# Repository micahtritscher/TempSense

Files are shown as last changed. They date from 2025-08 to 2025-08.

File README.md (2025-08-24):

# TempSense - ESP32-C3FH4 temperature logger Rev 0.1
*Micah Tritscher 07/25*

Wireless ESP32-C3FH4 based battery powered HDC1080DMBR temperature and humidty logger, with USB Type-C charging.

### Features
- I2C Texas Instruments HDC1080DMBR humidity and temperature sensor
- Impedance matched PCB antenna from TI AN043 application: https://www.ti.com/lit/an/swra117d/swra117d.pdf
- USB Type-C charging and programming
- BQ24074RGTR charging circuit (Designed for 500 mAh LiPO battery)
- Compact design at 25 mm x 50 mm

### Images
KiCAD 9.0 Renders
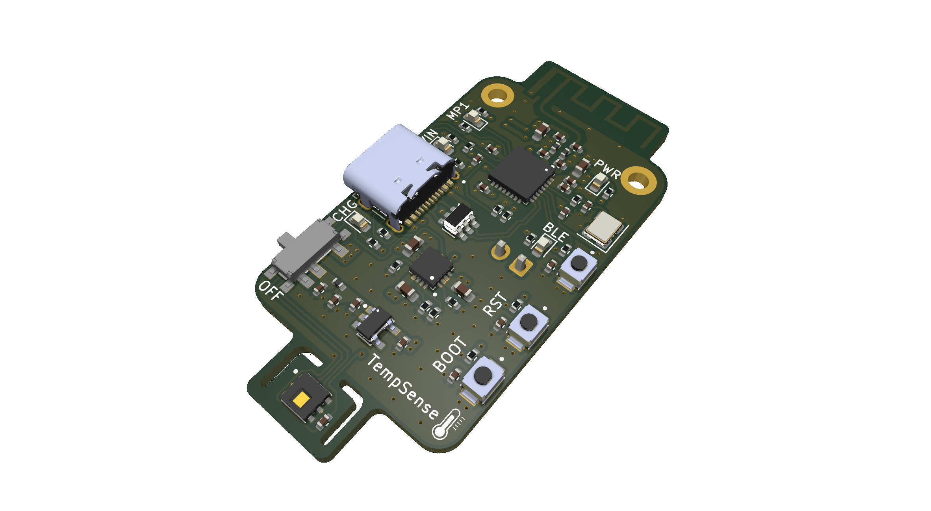
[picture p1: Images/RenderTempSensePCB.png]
PCB Render

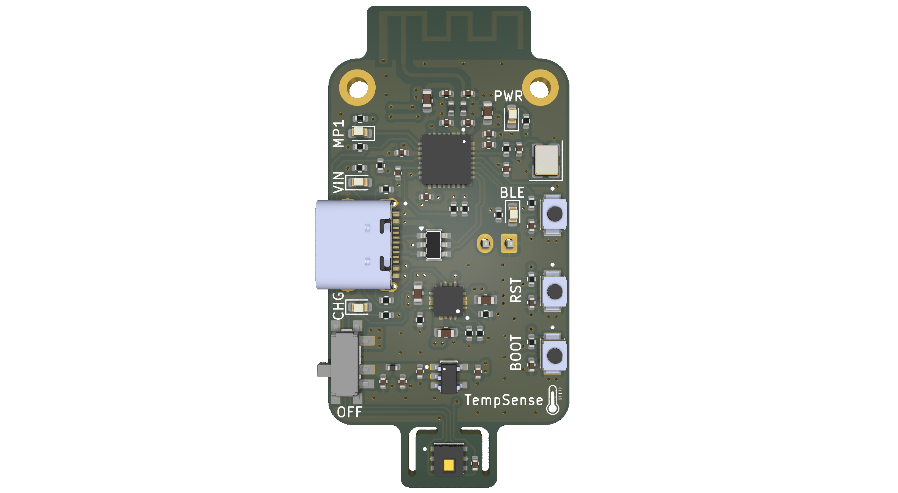
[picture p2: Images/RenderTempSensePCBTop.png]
PCB Render

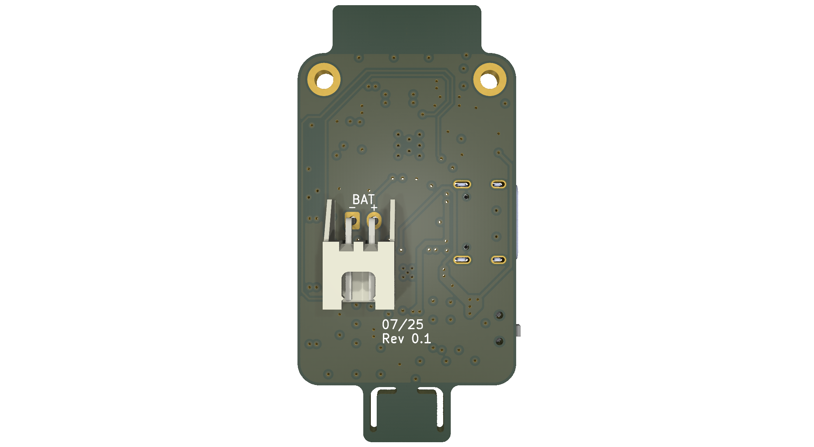
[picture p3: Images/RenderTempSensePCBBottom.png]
PCB Render

Manufactured by JLCPCB, assembled by hand
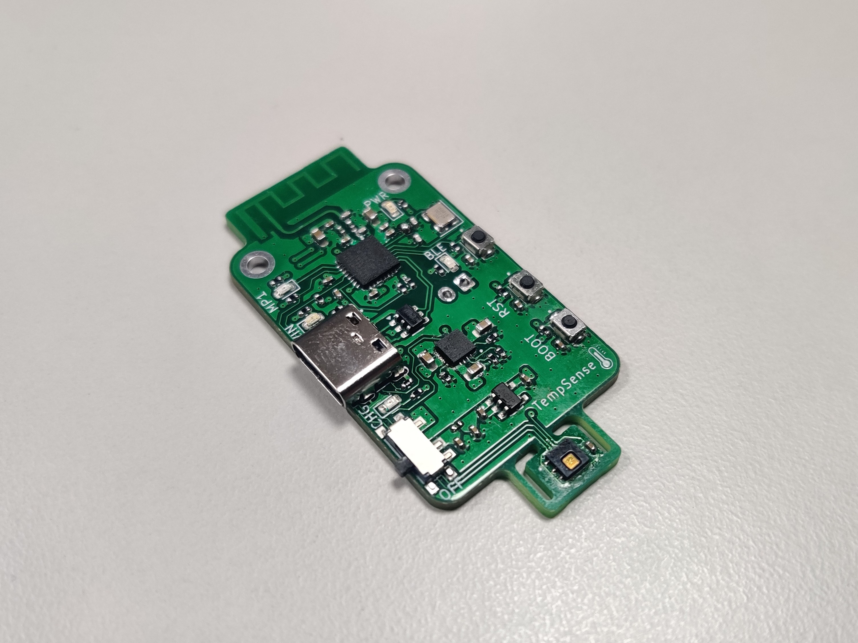
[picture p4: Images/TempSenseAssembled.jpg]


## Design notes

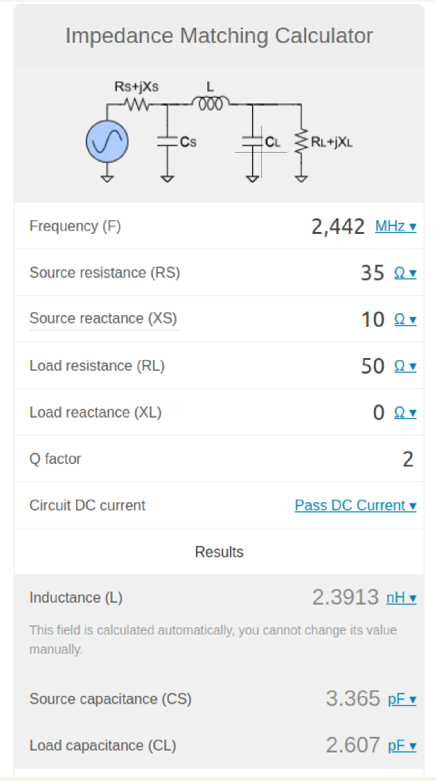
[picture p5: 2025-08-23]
Electrical/Impedance matching network.png

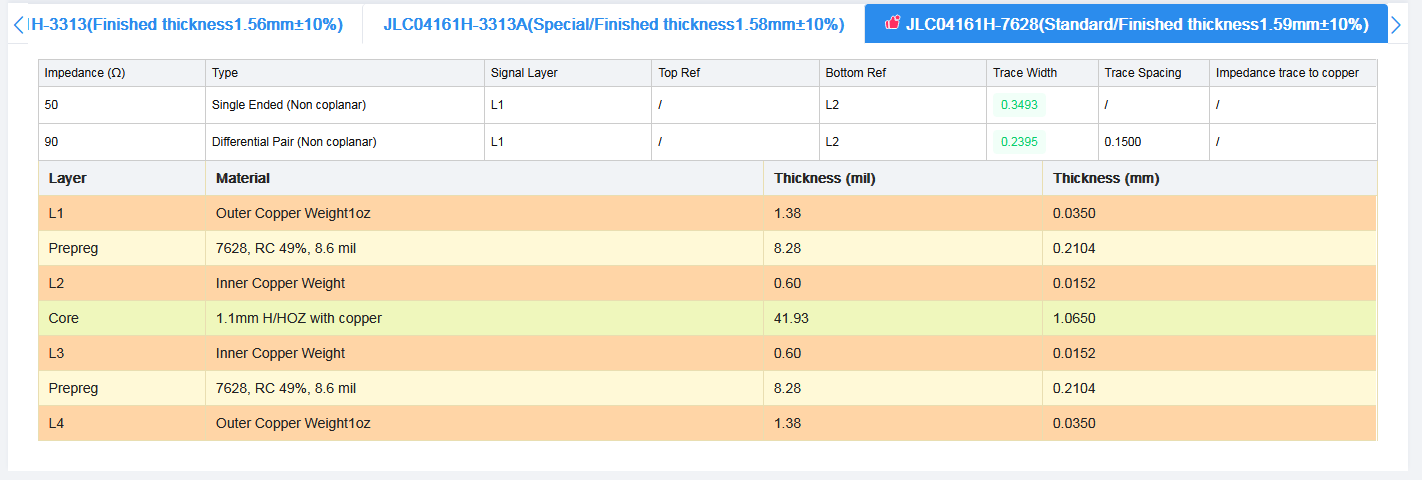
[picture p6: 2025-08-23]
Electrical/Impedance traces calcualtions.png

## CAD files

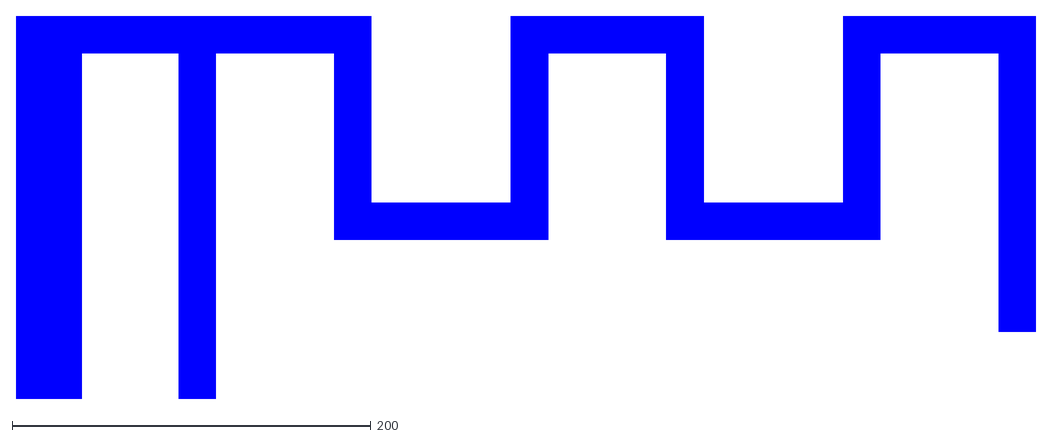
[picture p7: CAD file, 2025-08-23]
Electrical/IFA_USB.dxf
567.9 x 213.2

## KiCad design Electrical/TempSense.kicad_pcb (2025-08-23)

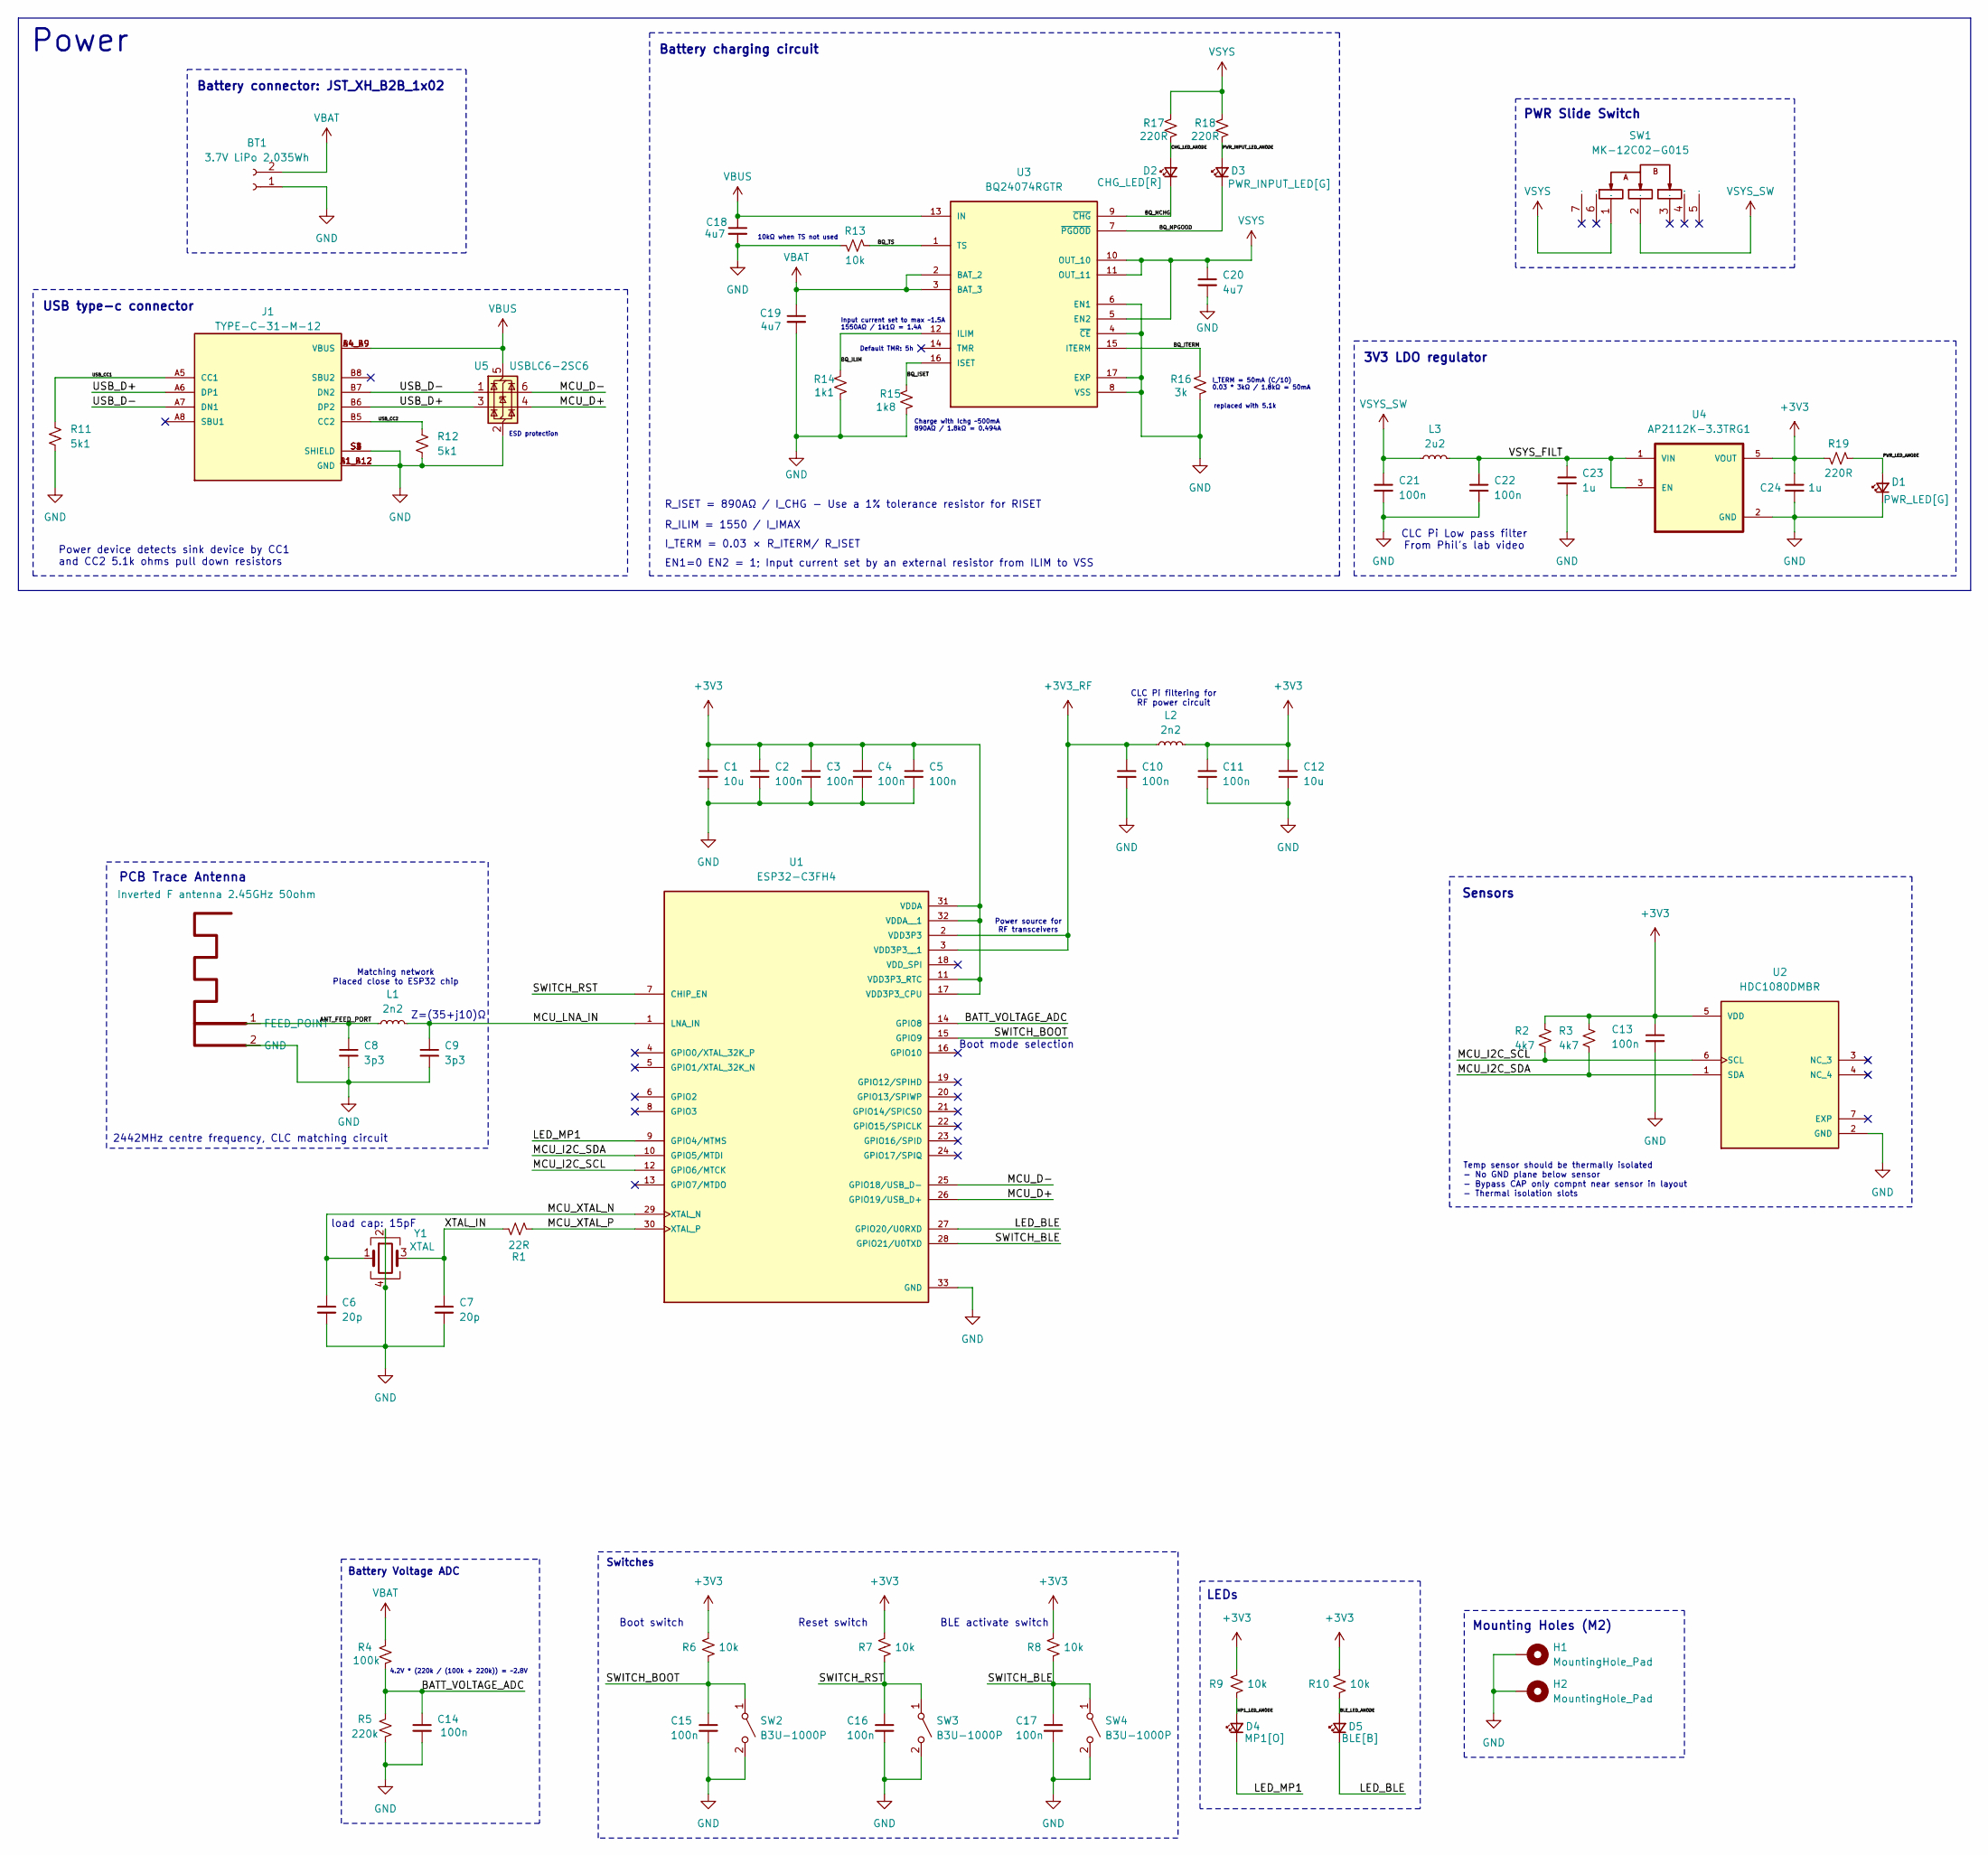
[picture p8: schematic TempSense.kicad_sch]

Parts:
ANT1: Inverted F antenna 2.45GHz 50ohm; Inverted_F_Meandered_Antenna_2.45GHz
BT1: 3.7V LiPo 2.035Wh; JST_XH_S2B-XH-A_1x02_P2.50mm_Horizontal
C1, C12: 10u; C_0603_1608Metric
C2, C3, C4, C5, C10, C11, C13, C14, C15, C16, C17, C21, C22: 100n; C_0402_1005Metric
C6, C7: 20p; C_0402_1005Metric
C8, C9: 3p3; C_0402_1005Metric
C18, C19, C20: 4u7; C_0603_1608Metric
C23, C24: 1u; C_0402_1005Metric
D1: PWR_LED[G]; LED_0603_1608Metric
D2: CHG_LED[R]; LED_0603_1608Metric
D3: PWR_INPUT_LED[G]; LED_0603_1608Metric
D4: MP1[O]; LED_0603_1608Metric
D5: BLE[B]; LED_0603_1608Metric
H1, H2: MountingHole_Pad; MountingHole_2.2mm_M2_DIN965_Pad
J1: TYPE-C-31-M-12; HRO_TYPE-C-31-M-12; PARTREV 2020.12.08
L1, L2: 2n2; L_0402_1005Metric
L3: 2u2; L_0402_1005Metric
R1: 22R; R_0402_1005Metric
R2, R3: 4k7; R_0402_1005Metric
R4: 100k; R_0402_1005Metric
R5: 220k; R_0402_1005Metric
R6, R7, R8, R9, R10, R13: 10k; R_0402_1005Metric
R11, R12: 5k1; R_0402_1005Metric
R14: 1k1; R_0402_1005Metric
R15: 1k8; R_0402_1005Metric
R16: 3k; R_0402_1005Metric
R17, R18, R19: 220R; R_0402_1005Metric
SW1: MK-12C02-G015; SW-SMD_G-SWITCH_MK-12C02-G015; Manufacturer Part MK-12C02-G015
SW2, SW3, SW4: B3U-1000P; SW_B3U-1000P
U1: ESP32-C3FH4; PARTREV 2.0
U2: HDC1080DMBR; PARTREV A
U3: BQ24074RGTR; PARTREV M
U4: AP2112K-3.3TRG1; PARTREV 2-2
U5: USBLC6-2SC6; SOT-23-6
Y1: XTAL; Crystal_SMD_3225-4Pin_3.2x2.5mm

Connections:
+3V3: C1.1, C2.1, C3.1, C4.1, C5.1, C11.1, C12.1, C13.1, C24.1, L2.2, R2.1, R3.1, R6.1, R7.1, R8.1, R9.1, R10.1, R19.2, U1.11 (VDD3P3_RTC), U1.17 (VDD3P3_CPU), U1.31 (VDDA), U1.32 (VDDA__1), U2.5 (VDD), U4.5 (VOUT)
+3V3_RF: C10.1, L2.1, U1.2 (VDD3P3), U1.3 (VDD3P3__1)
/ANT_FEED_PORT: ANT1.1 (FEED_POINT), C8.1, L1.1
/BATT_VOLTAGE_ADC: C14.1, R4.2, R5.1, U1.14 (GPIO8)
/BLE_LED_ANODE: D5.2 (A), R10.2
/BQ_ILIM: R14.2, U3.12 (ILIM)
/BQ_ISET: R15.2, U3.16 (ISET)
/BQ_ITERM: R16.2, U3.15 (ITERM)
/BQ_NCHG: D2.1 (K), U3.9 (~CHG)
/BQ_NPGOOD: D3.1 (K), U3.7 (~PGOOD)
/BQ_TS: R13.1, U3.1 (TS)
/CHG_LED_ANODE: D2.2 (A), R17.2
/LED_BLE: D5.1 (K), U1.27 (GPIO20/U0RXD)
/LED_MP1: D4.1 (K), U1.9 (GPIO4/MTMS)
/MCU_D+: U1.26 (GPIO19/USB_D+), U5.4 (I/O2)
/MCU_D-: U1.25 (GPIO18/USB_D-), U5.6 (I/O1)
/MCU_I2C_SCL: R2.2, U1.12 (GPIO6/MTCK), U2.6 (SCL)
/MCU_I2C_SDA: R3.2, U1.10 (GPIO5/MTDI), U2.1 (SDA)
/MCU_LNA_IN: C9.1, L1.2, U1.1 (LNA_IN)
/MCU_XTAL_N: C6.1, U1.29 (XTAL_N), Y1.1
/MCU_XTAL_P: R1.1, U1.30 (XTAL_P)
/MP1_LED_ANODE: D4.2 (A), R9.2
/PWR_INPUT_LED_ANODE: D3.2 (A), R18.2
/PWR_LED_ANODE: D1.2 (A), R19.1
/SWITCH_BLE: C17.1, R8.2, SW4.1 (A), U1.28 (GPIO21/U0TXD)
/SWITCH_BOOT: C15.1, R6.2, SW2.1 (A), U1.15 (GPIO9)
/SWITCH_RST: C16.1, R7.2, SW3.1 (A), U1.7 (CHIP_EN)
/USB_CC1: J1.A5 (CC1), R11.2
/USB_CC2: J1.B5 (CC2), R12.2
/USB_D+: J1.A6 (DP1), J1.B6 (DP2), U5.3 (I/O2)
/USB_D-: J1.A7 (DN1), J1.B7 (DN2), U5.1 (I/O1)
/VSYS_FILT: C22.1, C23.1, L3.2, U4.1 (VIN), U4.3 (EN)
/XTAL_IN: C7.1, R1.2, Y1.3
GND: ANT1.2 (GND), BT1.1, C1.2, C2.2, C3.2, C4.2, C5.2, C6.2, C7.2, C8.2, C9.2, C10.2, C11.2, C12.2, C13.2, C14.2, C15.2, C16.2, C17.2, C18.2, C19.2, C20.2, C21.2, C22.2, C23.2, C24.2, D1.1 (K), H1.1, H2.1, J1.A1_B12 (GND), J1.B1_A12 (GND), J1.S1 (SHIELD), J1.S2 (SHIELD), J1.S3 (SHIELD), J1.S4 (SHIELD), R5.2, R11.1, R12.1, R13.2, R14.1, R15.1, R16.1, SW2.2 (B), SW3.2 (B), SW4.2 (B), U1.33 (GND), U2.2 (GND), U3.4 (~CE), U3.6 (EN1), U3.8 (VSS), U3.17 (EXP), U4.2 (GND), U5.2 (GND), Y1.2, Y1.4; also elsewhere on the board
VBAT: BT1.2, C19.1, R4.1, U3.2 (BAT_2), U3.3 (BAT_3); also elsewhere on the board
VBUS: C18.1, J1.A4_B9 (VBUS), J1.B4_A9 (VBUS), U3.13 (IN), U5.5 (VBUS)
VSYS: C20.1, R17.1, R18.1, SW1.1, U3.5 (EN2), U3.10 (OUT_10), U3.11 (OUT_11)
VSYS_SW: C21.1, L3.1, SW1.2

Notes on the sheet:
load cap: 15pF
Charge with Ichg ~500mA 890AΩ / 1.8kΩ = 0.494A
PWR Slide Switch
Battery charging circuit
Z=(35+j10)Ω
R_ILIM = 1550 / I_IMAX
Mounting Holes (M2)
Power device detects sink device by CC1 and CC2 5.1k ohms pull down resistors
I_TERM = 50mA (C/10) 0.03 * 3kΩ / 1.8kΩ = 50mA
Battery Voltage ADC
Boot mode selection
Reset switch
Power source for RF transceivers
EN1=0 EN2 = 1; Input current set by an external resistor from ILIM to VSS
Input current set to max ~1.5A 1550AΩ / 1k1Ω = 1.4A
Sensors
BLE activate switch
CLC Pi filtering for RF power circuit
Matching network Placed close to ESP32 chip
I_TERM = 0.03 × R_ITERM/ R_ISET
R_ISET = 890AΩ / I_CHG
Boot switch
LEDs
ESD protection
CLC Pi Low pass filter From Phil's lab video
Switches
USB type-c connector
replaced with 5.1k
PCB Trace Antenna
Battery connector: JST_XH_B2B_1x02
4.2V * (220k / (100k + 220k)) = ~2.8V
Power
- Use a 1% tolerance resistor for RISET
Default TMR: 5h
10kΩ when TS not used
Temp sensor should be thermally isolated - No GND plane below sensor - Bypass CAP only compnt near sensor in layout - Thermal isolation slots
2442MHz centre frequency, CLC matching circuit
3V3 LDO regulator

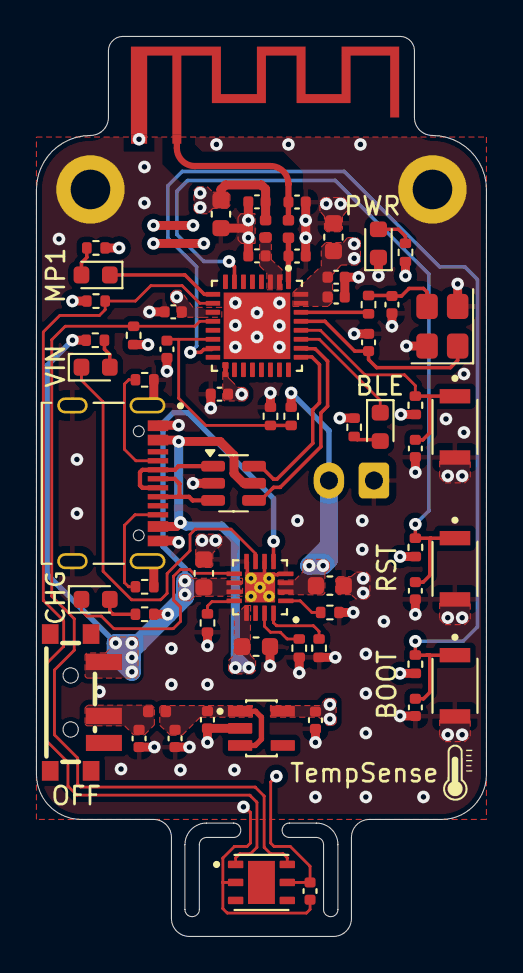
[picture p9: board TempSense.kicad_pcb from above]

Board: 4 copper layers, 25.0 x 50.0 mm, 66 parts (1 on the bottom side), 38 nets.

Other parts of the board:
BAT: 3.7V LiPo 2.035Wh; JST_XH_S2B-XH-A_1x02_P2.50mm_Horizontal

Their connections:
GND: BAT.1; also elsewhere on the board
VBAT: BAT.2; also elsewhere on the board

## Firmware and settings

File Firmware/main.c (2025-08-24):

#define HDC1080_TEMPERATURE         0x00
#define HDC1080_HUMIDTY             0x01
#define HDC1080_CONFIGURATION       0x02
#define HDC1080_SERIAL_ID_FIRST     0xFB
#define HDC1080_SERIAL_ID_MID       0xFC
#define HDC1080_SERIAL_ID_LAST      0xFD
#define HDC1080_MANUFACTURER_ID     0xFE
#define HDC1080_DEVICE_ID           0xFF
#define HDC1080_RESET               

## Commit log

2025-08-23 Uploaded PCB renders and photos
2025-08-23 Added KiCAD project folder
    [IFA_USB.dxf, TempSense.kicad_pcb, TempSense.kicad_sch]
2025-08-24 Added manufacturing folder
    [TempSense-B_Cu.gbl, TempSense-B_Mask.gbs, TempSense-B_Paste.gbp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]
